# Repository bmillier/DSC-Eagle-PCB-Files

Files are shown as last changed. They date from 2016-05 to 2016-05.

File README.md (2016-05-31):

# DSC-Eagle-PCB-Files
Eagle PCB and schematic files
These are the BRD and SCH files for the Arduino Shield, as well as the BRD file for the small PCB used for the DSC thermal head.
I had the Arduino Shield PCB fabricated at Osh Park Sales- 3 boards cost USD35

The DSC thermal head PCB is a PCB that I have used on previous DSC models, and was originally fabricated by Express PCB, using their own PCB 
software.
I have drawn this PCB in Eagle, and have included that file, although I have not had this board fabricated from this file yet.

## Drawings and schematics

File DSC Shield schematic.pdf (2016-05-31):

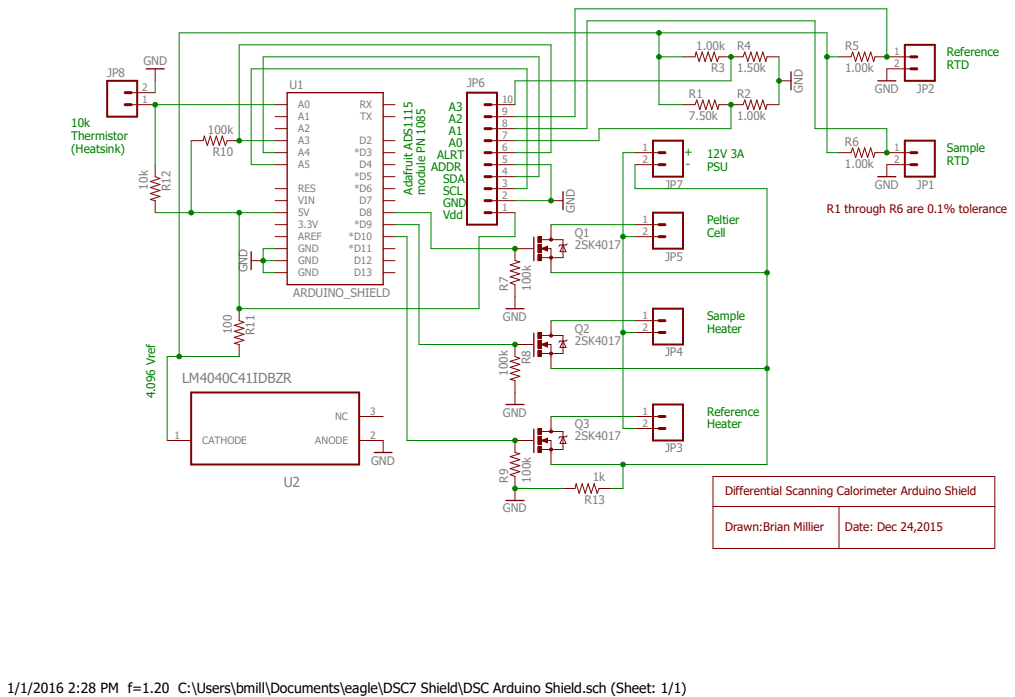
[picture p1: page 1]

1/1/2016 2:28 PM f=1.20 C:\Users\bmill\Documents\eagle\DSC7 Shield\DSC Arduino Shield.sch (Sheet: 1/1)

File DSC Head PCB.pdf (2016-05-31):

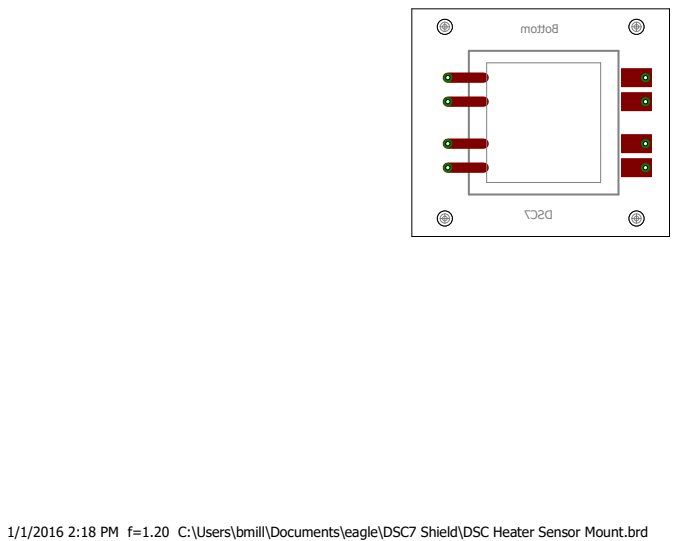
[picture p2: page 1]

1/1/2016 2:18 PM f=1.20 C:\Users\bmill\Documents\eagle\DSC7 Shield\DSC Heater Sensor Mount.brd

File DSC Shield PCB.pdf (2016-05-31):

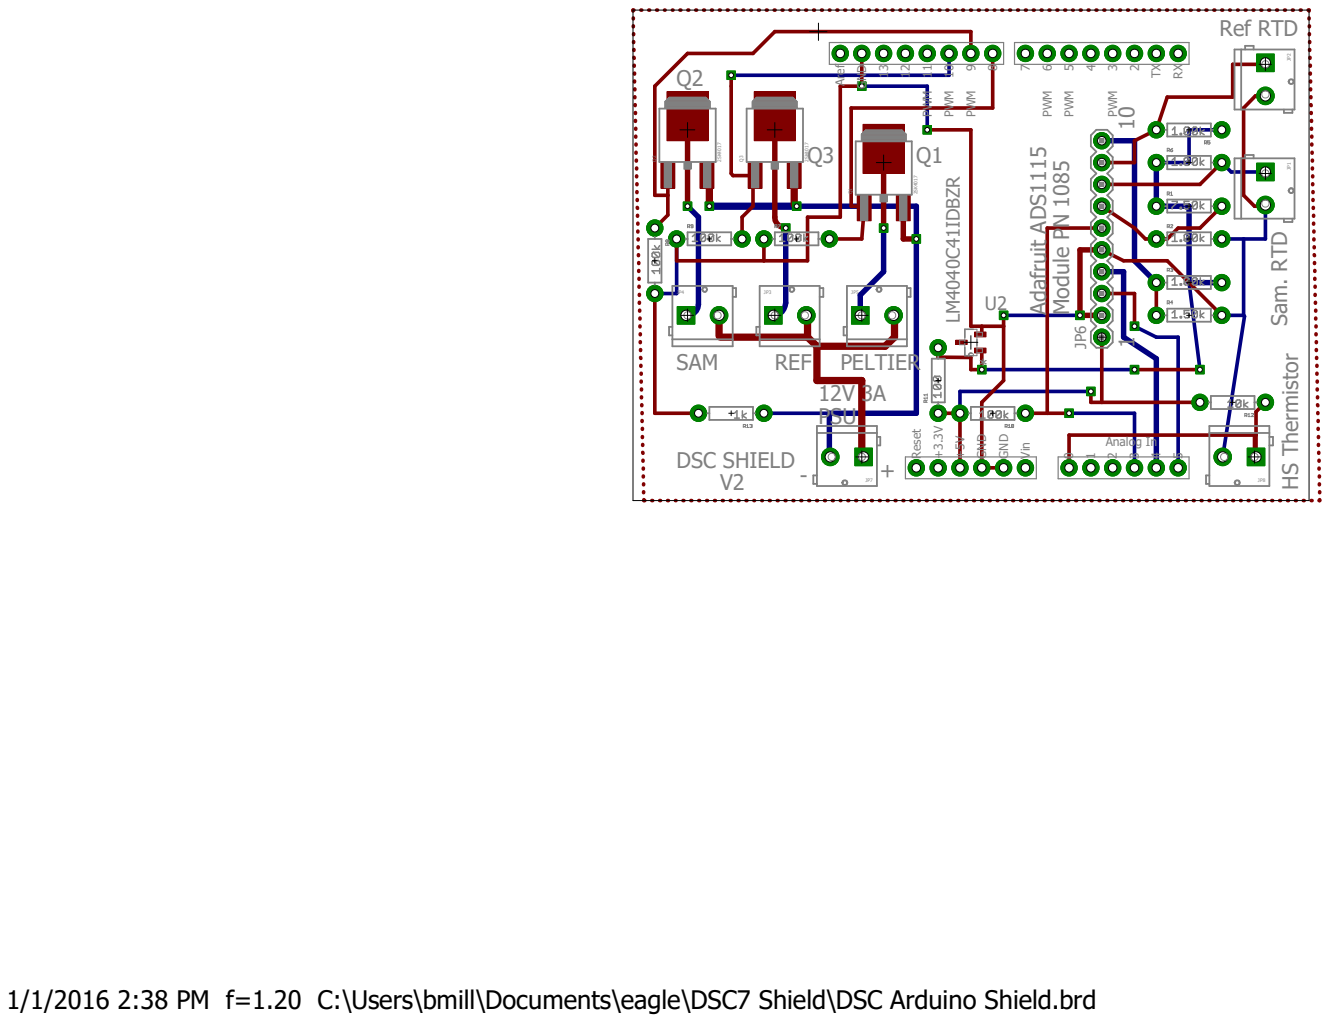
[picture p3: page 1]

2TXRX PWM PWM PWM PWM PWM PWM

1/1/2016 2:38 PM f=1.20 C:\Users\bmill\Documents\eagle\DSC7 Shield\DSC Arduino Shield.brd Adafruit ADS1115 Module PN ¹⁰⁸⁵

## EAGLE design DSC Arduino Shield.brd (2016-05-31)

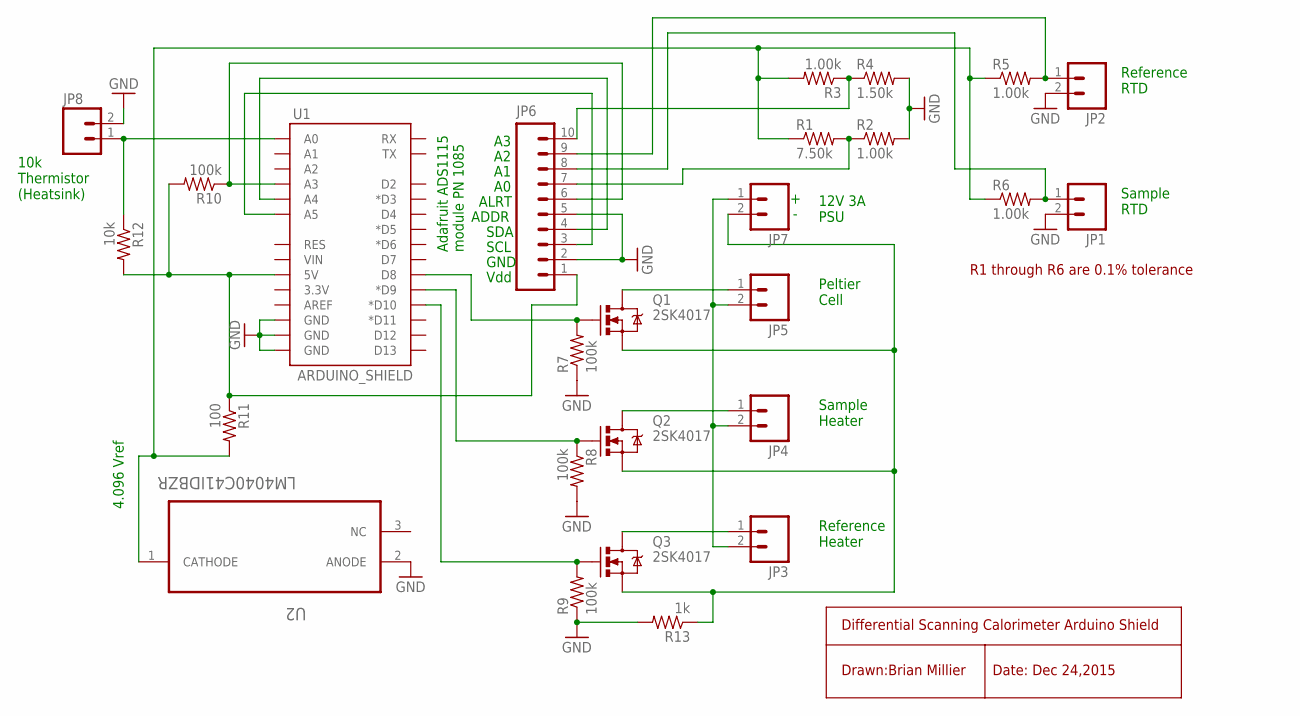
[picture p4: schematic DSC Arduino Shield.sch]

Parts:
JP1, JP2, JP3, JP4, JP5, JP7, JP8: M023.5MM_LOCK; SCREWTERMINAL-3.5MM-2_LOCK
JP6: M10SILK_FEMALE_PTH; 1X10
Q1, Q2, Q3: 2SK4017; DPAK
R1: 7.50k; AXIAL-0.3
R2, R3, R5, R6: 1.00k; AXIAL-0.3
R4: 1.50k; AXIAL-0.3
R7, R8, R9, R10: 100k; AXIAL-0.3
R11: 100; AXIAL-0.3
R12: 10k; AXIAL-0.3
R13: 1k; AXIAL-0.3
U1: ARDUINO_SHIELD; DUEMILANOVE_VIAS
U2: LM4040C41IDBZR; SOT95P237X112-3N

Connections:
GND: JP1.2, JP2.2, JP6.2, JP6.5, JP8.2, R2.P$2 (2), R4.P$2 (2), R7.P$1 (1), R8.P$2 (2), R9.P$1 (1), R13.P$2 (2), U1.GND@0 (GND), U1.GND@1 (GND), U1.GND@2 (GND), U2.2 (ANODE)
unnamed: Q1.1 (G), R7.P$2 (2), U1.D8
unnamed: Q2.1 (G), R8.P$1 (1), U1.D9 (*D9)
unnamed: Q3.1 (G), R9.P$2 (2), U1.D10 (*D10)
unnamed: JP5.1, Q1.4 (D)
unnamed: JP4.1, Q2.4 (D)
unnamed: JP3.1, Q3.4 (D)
unnamed: JP3.2, JP4.2, JP5.2, JP7.1
unnamed: JP6.7, R1.P$2 (2), R2.P$1 (1)
unnamed: JP6.10, R3.P$1 (1), R4.P$1 (1)
unnamed: JP6.1, R10.P$2 (2), R11.P$1 (1), R12.P$2 (2), U1.5V
unnamed: JP7.2, Q1.3 (S), Q2.3 (S), Q3.3 (S), R13.P$1 (1)
unnamed: JP6.3, U1.A5
unnamed: JP6.4, U1.A4
unnamed: JP6.6, R10.P$1 (1), U1.A3
unnamed: JP2.1, JP6.9, R5.P$2 (2)
unnamed: R1.P$1 (1), R3.P$2 (2), R5.P$1 (1), R6.P$1 (1), R11.P$2 (2), U2.1 (CATHODE)
unnamed: JP1.1, JP6.8, R6.P$2 (2)
unnamed: JP8.1, R12.P$1 (1), U1.A0

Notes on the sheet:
Peltier Cell
Sample Heater
Reference Heater
12V 3A PSU
Sample RTD
Reference RTD
10k Thermistor (Heatsink)
Adafruit ADS1115 module PN 1085
Vdd
GND
SCL
SDA
ADDR
ALRT
4.096 Vref
Differential Scanning Calorimeter Arduino Shield
Date: Dec 24,2015
Drawn:Brian Millier
R1 through R6 are 0.1% tolerance

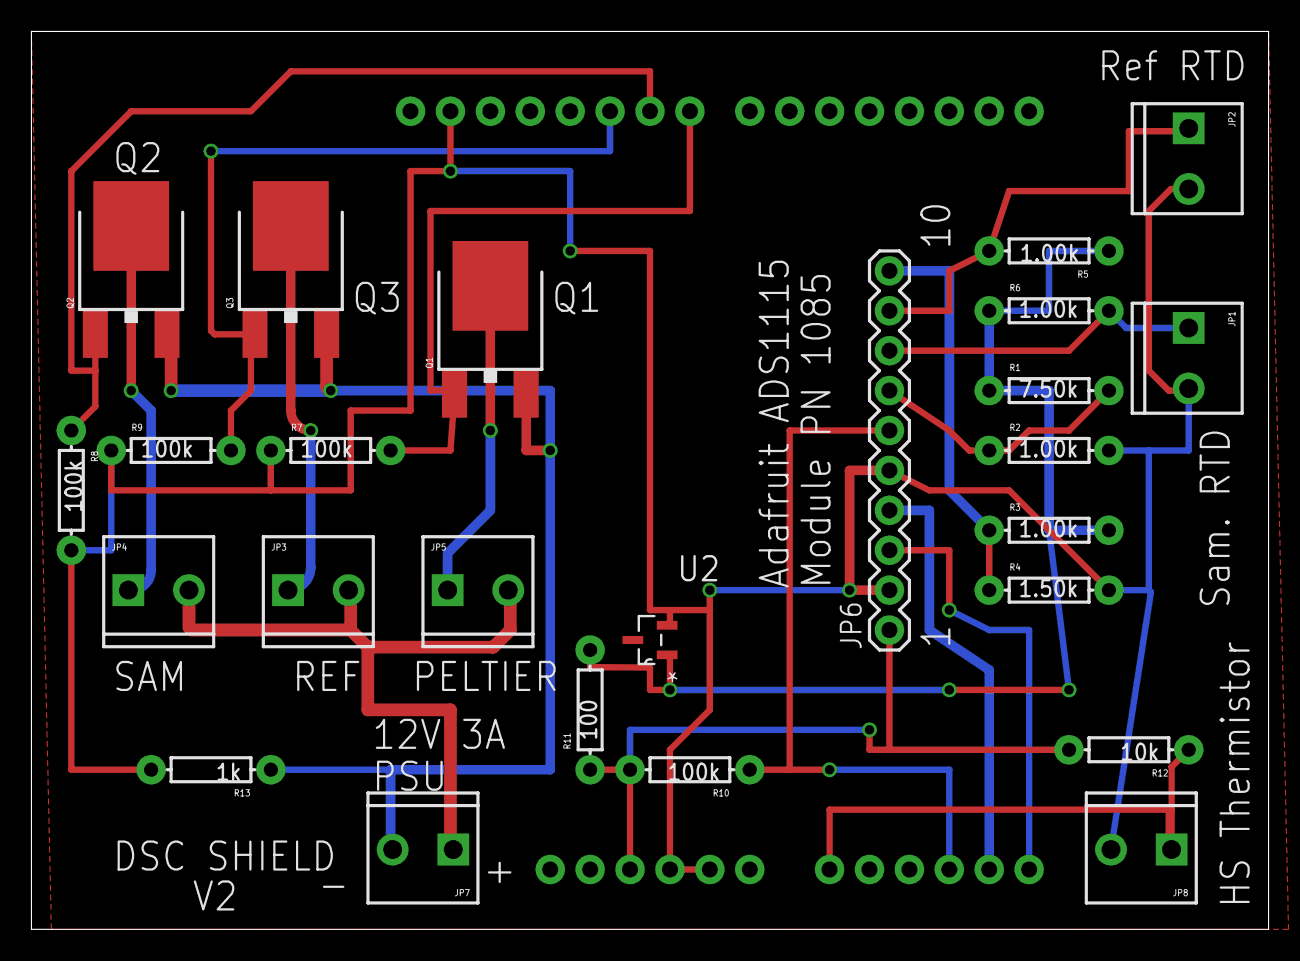
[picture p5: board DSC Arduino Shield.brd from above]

Board: 2 copper layers, 78.7 x 57.1 mm, 26 parts (0 on the bottom side), 19 nets.

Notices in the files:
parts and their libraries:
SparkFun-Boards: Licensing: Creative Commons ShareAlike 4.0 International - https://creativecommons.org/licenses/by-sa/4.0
